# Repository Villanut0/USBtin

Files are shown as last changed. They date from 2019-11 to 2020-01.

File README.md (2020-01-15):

# USBtin USB to CAN interface clone

USBtin is a simple USB to CAN interface. It can monitor CAN busses and transmit CAN messages. USBtin implements the USB CDC class and creates a virtual comport on the host computer.

**This PCB is a clone of the original project :** [USBtin](https://www.fischl.de/usbtin/)

It is almost the same as the original PCB. I made it to be able to mill it easily on my cheap milling machine.

## Features
* 65x32mm
* Single sided PCB with only 2 straps
* Same through-hole components as the original project ([Partlist](https://www.fischl.de/usbtin/#partlist))
* [Interactive BOM](http://htmlpreview.github.io/?https://github.com/Villanut0/USBtin/blob/master/bom/ibom.html)

## Screenshots
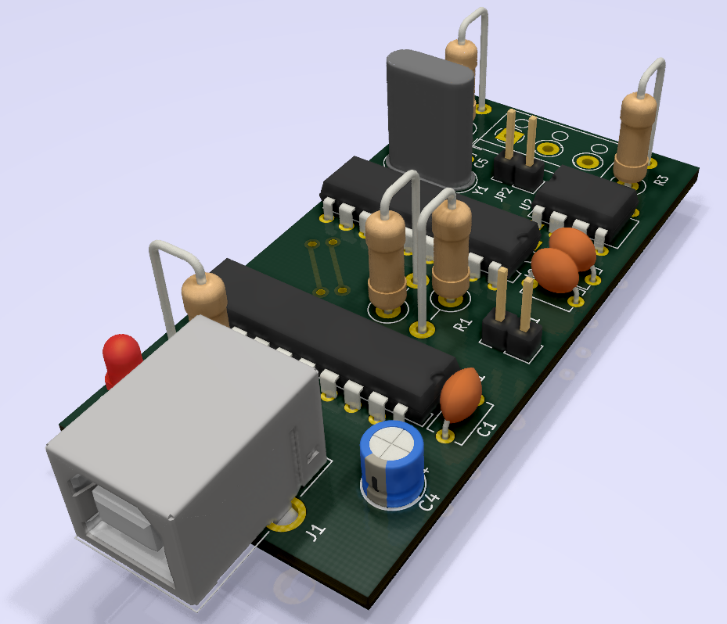
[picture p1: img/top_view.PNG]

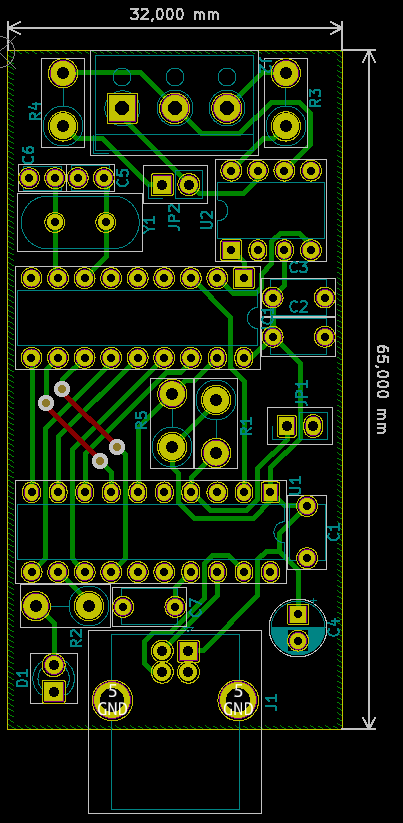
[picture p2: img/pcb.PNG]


## Enclosure
3D printed enclosure is available on [Thingiverse](https://www.thingiverse.com/thing:3976971)

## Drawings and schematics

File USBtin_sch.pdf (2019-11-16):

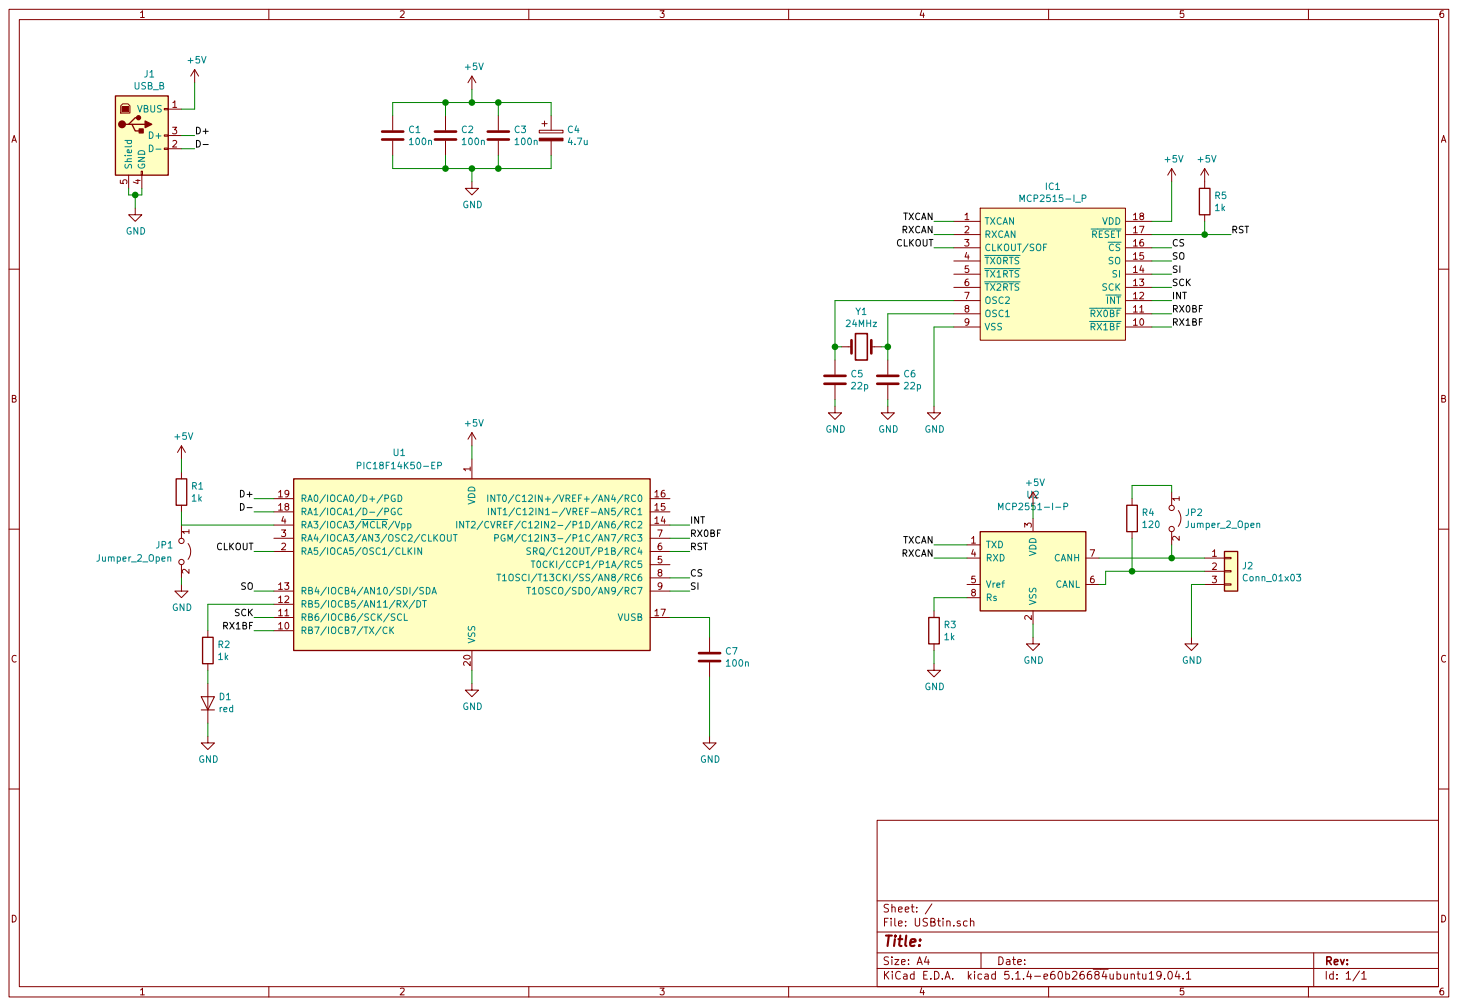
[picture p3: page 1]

1 RB7/IOCB7/TX/CK 10 RB6/IOCB6/SCK/SCL 11 RB5/IOCB5/AN11/RX/DT 12 RB4/IOCB4/AN10/SDI/SDA 13

3 RXD 4 Vref 5 CANL 6 CANH 7 Rs 8 U2 MCP2551-I-P C7

Id: 1/1 Title: File: USBtin.sch Sheet: /

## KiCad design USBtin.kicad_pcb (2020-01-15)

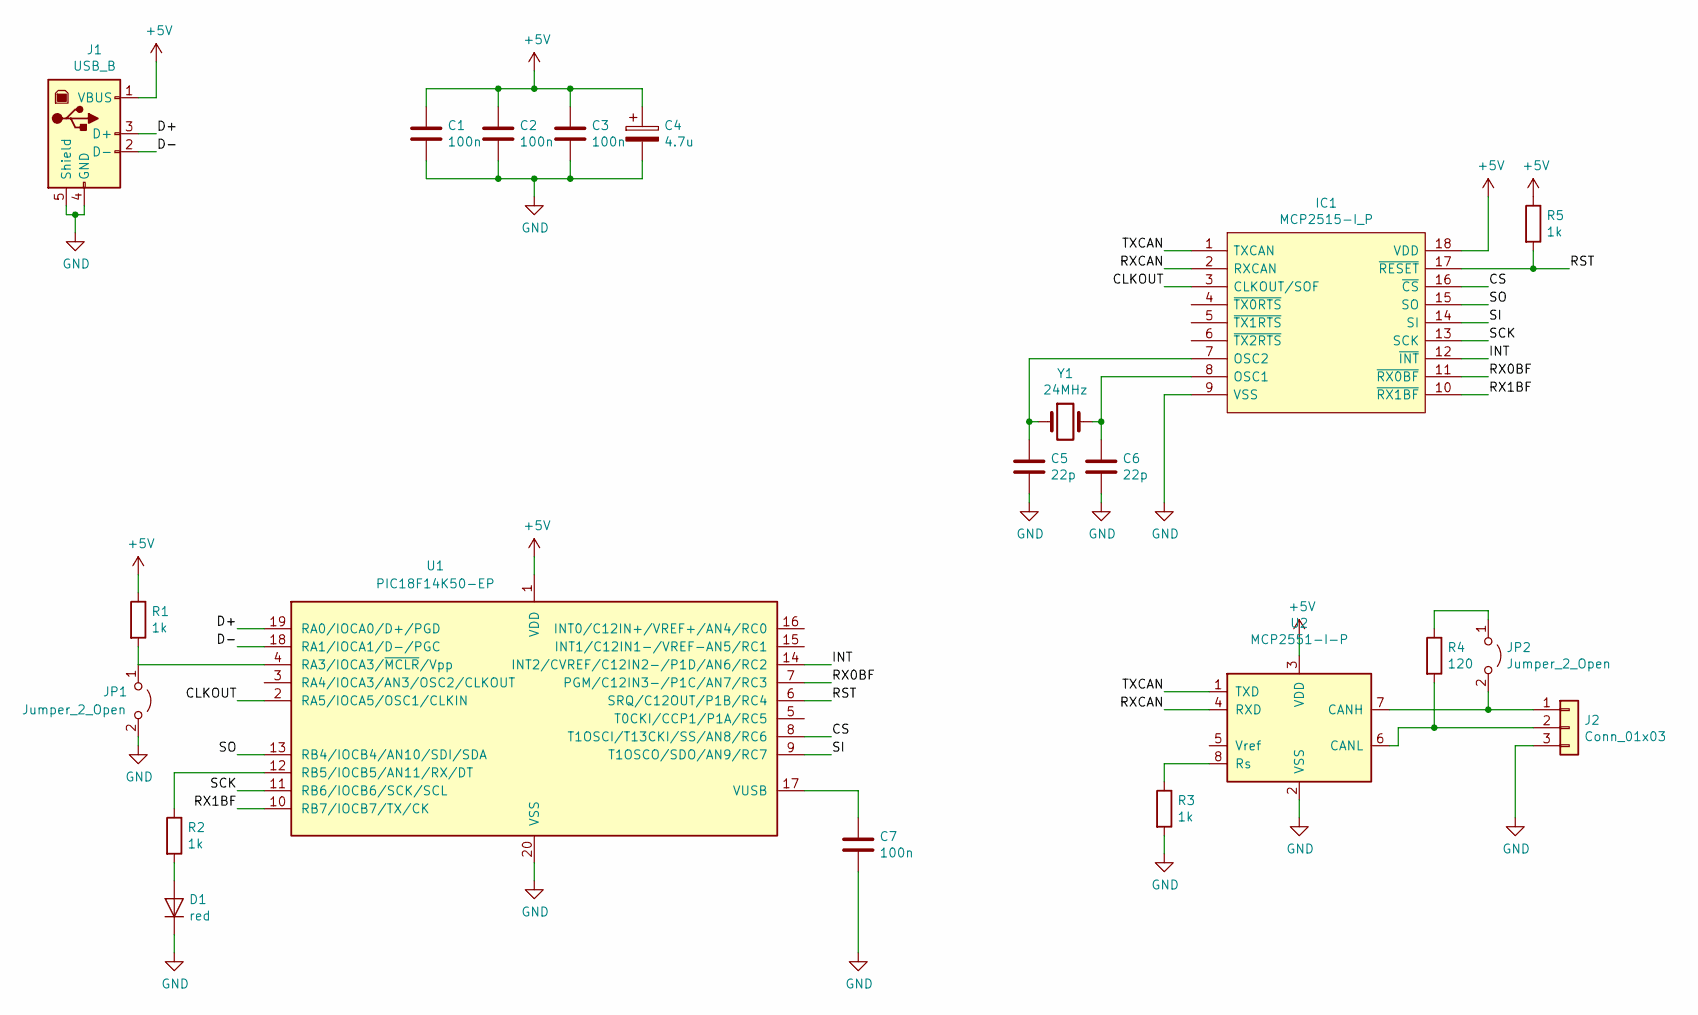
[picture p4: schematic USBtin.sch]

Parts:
C1, C2, C3, C7: 100n; C_Disc_D5.1mm_W3.2mm_P5.00mm
C4: 4.7u; CP_Radial_D5.0mm_P2.50mm
C5, C6: 22p; C_Disc_D3.4mm_W2.1mm_P2.50mm
D1: red; LED_D3.0mm
IC1: MCP2515-I_P; DIP-18_W7.62mm; Manufacturer_Part_Number MCP2515-I/P; Mouser Part Number 579-MCP2515-I/P
J1: USB_B; USB_B_OST_USB-B1HSxx_Horizontal
J2: Conn_01x03; TerminalBlock_RND_205-00002_1x03_P5.00mm_Horizontal
JP1, JP2: Jumper_2_Open; PinHeader_1x02_P2.54mm_Vertical
R1, R2, R3, R5: 1k; R_Axial_DIN0411_L9.9mm_D3.6mm_P5.08mm_Vertical
R4: 120; R_Axial_DIN0411_L9.9mm_D3.6mm_P5.08mm_Vertical
U1: PIC18F14K50-EP; DIP-20_W7.62mm
U2: MCP2551-I-P; DIP-8_W7.62mm
Y1: 24MHz; Crystal_HC49-U_Vertical

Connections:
+5V: C1.1, C2.1, C3.1, C4.1, IC1.18 (VDD), J1.1 (VBUS), R1.1, R5.1, U1.1 (VDD), U2.3 (VDD)
/CLKOUT: IC1.3 (CLKOUT/SOF), U1.2 (RA5/IOCA5/OSC1/CLKIN)
/CS: IC1.16 (~CS), U1.8 (T1OSCI/T13CKI/SS/AN8/RC6)
/D+: J1.3 (D+), U1.19 (RA0/IOCA0/D+/PGD)
/D-: J1.2 (D-), U1.18 (RA1/IOCA1/D-/PGC)
/INT: IC1.12 (~INT), U1.14 (INT2/CVREF/C12IN2-/P1D/AN6/RC2)
/RST: IC1.17 (~RESET), R5.2, U1.6 (SRQ/C12OUT/P1B/RC4)
/RX0BF: IC1.11 (~RX0BF), U1.7 (PGM/C12IN3-/P1C/AN7/RC3)
/RX1BF: IC1.10 (~RX1BF), U1.10 (RB7/IOCB7/TX/CK)
/RXCAN: IC1.2 (RXCAN), U2.4 (RXD)
/SCK: IC1.13 (SCK), U1.11 (RB6/IOCB6/SCK/SCL)
/SI: IC1.14 (SI), U1.9 (T1OSCO/SDO/AN9/RC7)
/SO: IC1.15 (SO), U1.13 (RB4/IOCB4/AN10/SDI/SDA)
/TXCAN: IC1.1 (TXCAN), U2.1 (TXD)
GND: C1.2, C2.2, C3.2, C4.2, C5.2, C6.2, C7.2, D1.1 (K), IC1.9 (VSS), J1.4 (GND), J1.5 (Shield), J2.3, JP1.2 (B), R3.2, U1.20 (VSS), U2.2 (VSS)
unnamed: C5.1, IC1.7 (OSC2), Y1.1
unnamed: C6.1, IC1.8 (OSC1), Y1.2
unnamed: C7.1, U1.17 (VUSB)
unnamed: D1.2 (A), R2.2
unnamed: J2.1, JP2.2 (B), U2.7 (CANH)
unnamed: J2.2, R4.2, U2.6 (CANL)
unnamed: JP1.1 (A), R1.2, U1.4 (RA3/IOCA3/~MCLR~/Vpp)
unnamed: JP2.1 (A), R4.1
unnamed: R2.1, U1.12 (RB5/IOCB5/AN11/RX/DT)
unnamed: R3.1, U2.8 (Rs)

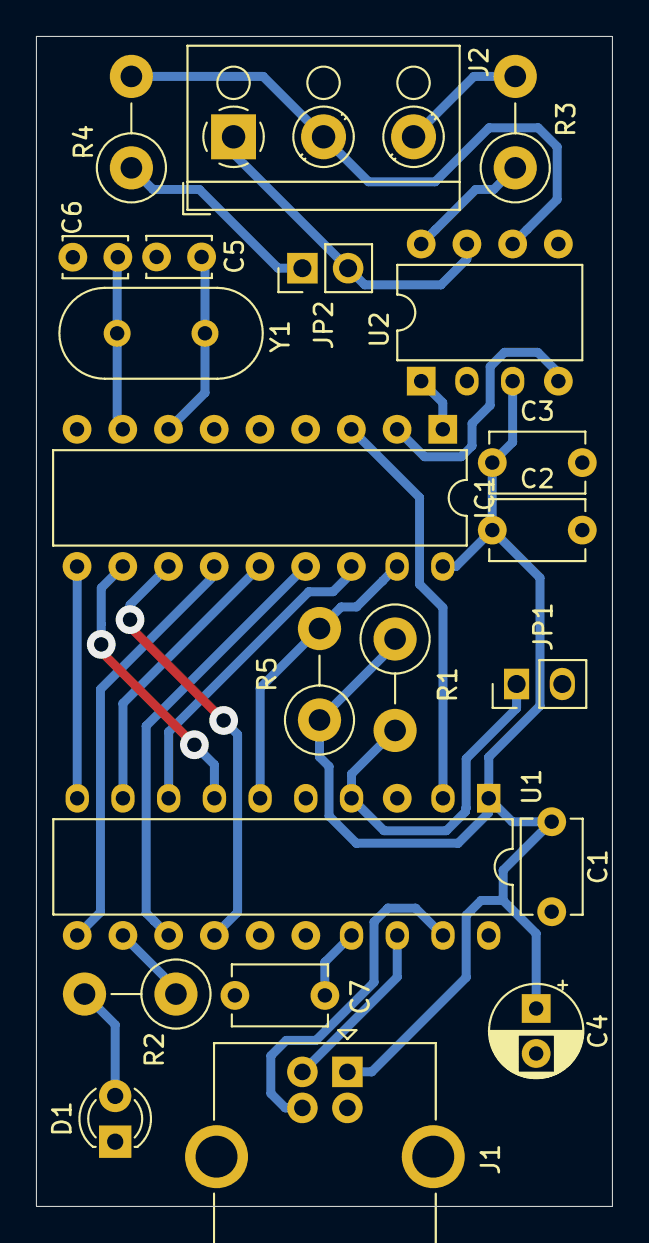
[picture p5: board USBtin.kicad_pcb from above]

Board: 2 copper layers, 32.0 x 65.0 mm, 21 parts (0 on the bottom side), 25 nets.

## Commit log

2019-10-20 schematic and pcb done
    [USBtin.kicad_pcb, USBtin.sch]
2019-10-23 changing C4 to a polarize capacitor
    [USBtin.kicad_pcb, USBtin.sch]
2019-10-24 adding origin
    [USBtin.kicad_pcb]
2019-10-25 rotate 90 degrees
    [USBtin.kicad_pcb]
2019-10-25 USB 3D model
    [USBtin.kicad_pcb]
2019-11-14 updated README, output files in gbr, schematic PDF
    [USBtin-B_Cu.gbr, USBtin-Edge_Cuts.gbr, USBtin-NPTH.drl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]
2019-11-16 removing comment on schematic
    [USBtin.sch]
2020-01-15 Interactive BOM and update README
    [USBtin.kicad_pcb]
2020-01-15 Fix interactive BOM link
